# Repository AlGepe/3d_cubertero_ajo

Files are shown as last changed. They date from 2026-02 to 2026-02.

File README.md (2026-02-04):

# 3d_cubertero_ajo
3D designs for cutlery drawer at home

## Progress Overview
- [x] Get dimensions
- [x] Validate dimensions IRL
- [ ] Create cutouts
- [ ] Create full blocks
- [ ] Print everything

## The goal

Organise the cutlery drawer by making custom 3D printed inserts to fit especific cutlery in the generic spaces already existing in the store-bough cutlery insert.

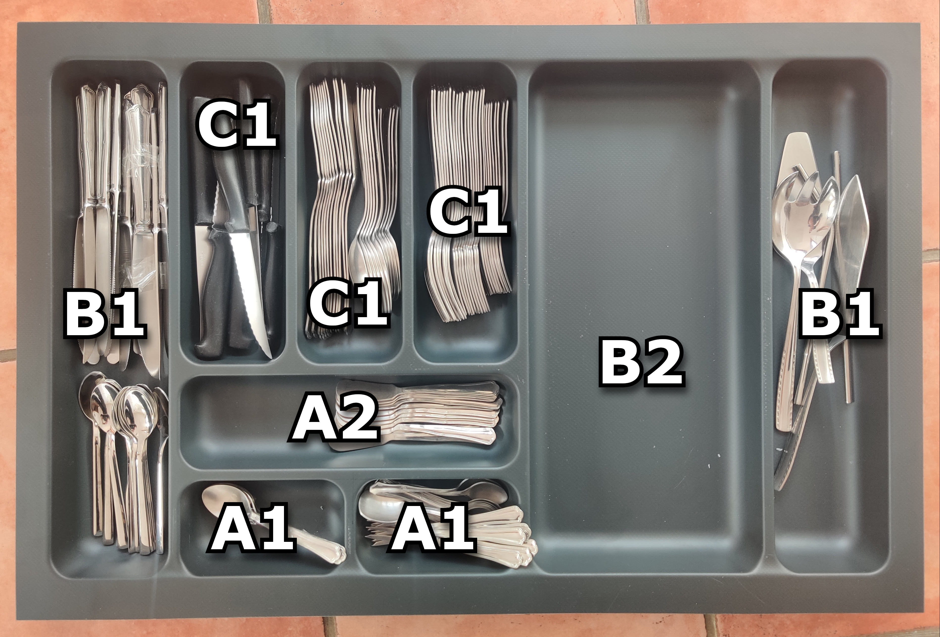
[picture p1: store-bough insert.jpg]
cubertero comprado


## Project breakdown

### Get dimensions [done]

First we will take measurements of the store-bought insert and try to guess the curvature radius for each dimension. Perfect fit is not required: the aim is functional, no perfect.

The measurements are stored in the corresponding files, each space has been named according to the picture above.

### Validate dimensions IRL [partially done]

Once the measurements are gathered a series of quick 3D printed prototypes will be used to validate the dimensions and adjust as needed to achieve a satisfactory fit in their corresposnding spaces

It is important to note that due to the size of the insert most will require to be printed in pieces and be connected aftewards. This will be done in Creality Printpe slicer using the dove tail option in the cutting tool. Tolerances will need to be tested. This might need to be tested separately, since the prototyping settings for printing will be optimized for speed and not precision.

### Create cutouts

Each type of cutlery will need an outline to be created and a cutout piece to be printed and tested. Other features that will need to be tested are the depth and the shape and size of the side space within each insert to make picking up the cutlery easy no matter now many pieces are left

### Print everything

This stage requires final layout of the cutlery to be decided. A compromise between space efficiency and ease of use will need to be agreed on.

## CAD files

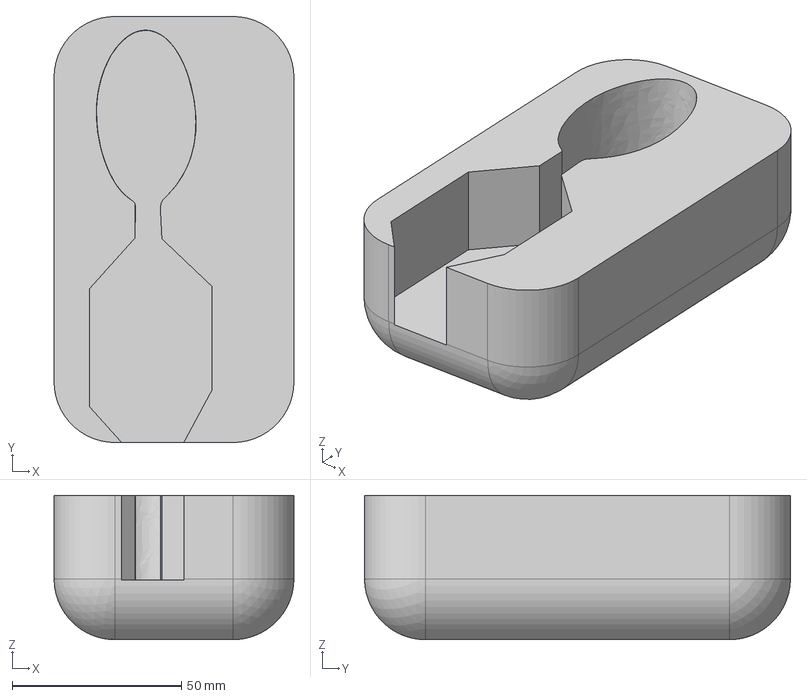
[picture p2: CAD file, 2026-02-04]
block with cutout.step
71.0 x 126.0 x 42.7 mm

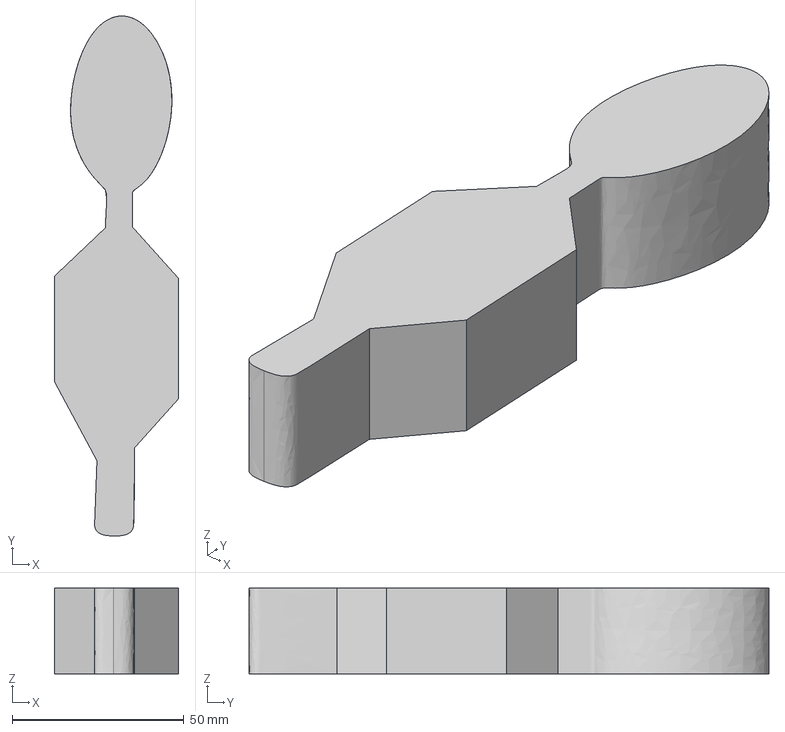
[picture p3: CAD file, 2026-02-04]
outline_teaspoon.step
36.2 x 151.4 x 25.0 mm

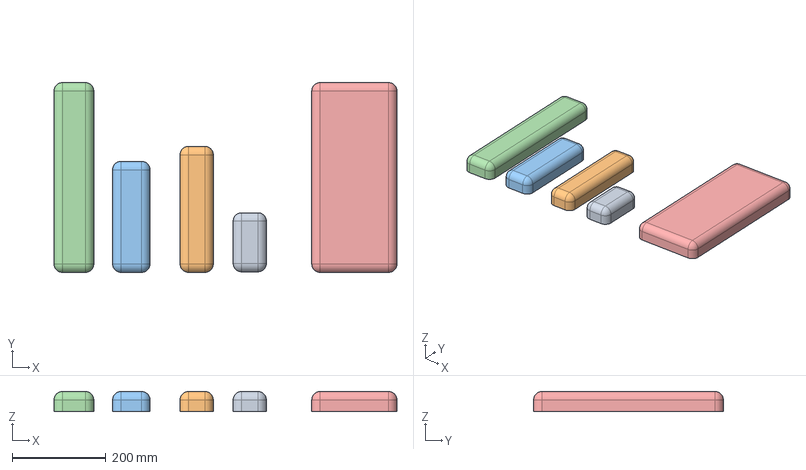
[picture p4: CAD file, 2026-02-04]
Cubertero_medidas.stp
732.0 x 405.0 x 42.7 mm

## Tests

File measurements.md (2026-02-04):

# Measurements (store-bought insert)
## Global
Thickness of plastic = 1.68 mm
Radius (fillet) = 18.80 mm (approx)
Depth = 42.7 mm
## A1
width = 75 mm
length = 130 mm
## A2
width = 75 mm
length = 273 mm
## B1
width = 90 mm
length = 273 mm
## B1
width = 187 mm
length = 410 mm
## C1
width = 85 mm
length = 242 mm

## Adjustment for 3D modelling

All width/length measurements are taking at the widest/longest points so a -4 mm correction should be applied to the 3D model. This will leavea small gap at the top but has proven to give a tight enough fit that the printed inserts don't move around

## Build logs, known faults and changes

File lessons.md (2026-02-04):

# Lessons learn

1. The spaces in the store bought insert are not very precise but have a slight flexibility
2. The spaces in the store bought insert do not have walls at 90º the flare out ever so slightly
3. To correct for the flare a 18 mm fillet and -4 mm to the maximum dimensions seems to do the trick
4. Oversizing the outline by 1 mm is the correct choice. 1 mm seems too much, but testing 0.5 mm makes the fit way too tight.
5. The best approach is to create 3D objects for each item required (bought insert space, cutlery piece, finger hole) and combine them later, probably in the slicer
6. On dovetails in Creality Print, a tolerance value of 0.4 mm still requires deburring/sanding and force. Can't tell if it's due to the print quality of prototypes, but better to set 0.5 mm for final pieces and then reassess
7. A2 requires a -5 mm correction on the length

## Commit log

2026-02-04 Added picture of storebought insert and naming
2026-02-04 Added 3D models with correct measurements
    [Cubertero_medidas.stp]
2026-02-04 Added teaspoon cutout
    Included a sample block with the cutout created for test printing
    [block with cutout.step, outline_teaspoon.step]
2026-02-04 New lessons
    Added additional notes on design adjustments and tolerances for 3D printing.
